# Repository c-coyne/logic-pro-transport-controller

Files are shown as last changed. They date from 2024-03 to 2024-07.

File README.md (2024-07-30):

# Logic Pro Transport Controller

[Logic Pro](https://www.apple.com/logic-pro/) is a professional music recording and production software for Mac that essentially brings an entire music recording studio to your laptop. It's perhaps a bit deceiving given how accessible the software is, but Logic Pro is so professional that a number of big-time musicians have used it to produce albums, including Ed Sheeran (Shape of You), Billie Eilish (most of her music), Taylor Swift (Speak), and The Strokes (Is This It). The DAW (digital audio workstation) is consistently ranked as one of the best available, and was again [rated highly for 2024](https://www.musicradar.com/news/the-best-daws-the-best-music-production-software-for-pc-and-mac).

Likely the most frequently used commands in Logic Pro (at least on the recording side) are contained in a part of the DAW known as the _transport controls_. Below is a snapshot of the transport buttons:

<p align="center">
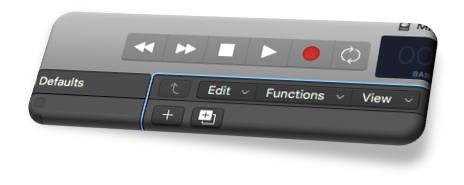
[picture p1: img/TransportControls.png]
Transport controls in Logic Pro
  
</p>

Here's where you'll find options for _return to the beginning_, _rewind_, _fast forward_, _stop_, _play_, and _record_ - in other words, the essential commands for navigating the track. These commands are used so frequently used that you can buy a separate device that facilitates transport control, or a _transport controller_. There are some really interesting controllers on the market, like [this one](https://www.presonus.com/en-US/controllers/control-surface/faderport-series/2777100203.html) from PreSonus. However, these transport controllers are typically rather expensive (anywhere from \$200 to \$500 or more) and aren't customizable. They also tend to be overkill if you're only using a few buttons, plus they require an extra free hand to use.

This is where this project was born. The Logic Pro transport controller designed and built here is entirely customizable, is intended to be operated as a footswitch (so your hands are free to play the music), is a simple plug-and-play (no drivers required), and adds an element of feedback in the form of LEDs. It's certainly more function over form, but its vintage Fender footswitch body and underbody LEDs also make for a cool addition to the recording studio. Happy recording.

## 1. :notes: Project Description
The Logic Pro transport controller detailed here is a simple addition to a vintage 4-button Fender footswitch intended for the Mustang series of guitar amplifiers. I added a microcontroller (Arduino Micro), cast LED strip lights in epoxy underneath the footswitch, and designed and 3D-printed new custom end caps to make room for the additional wiring and new connection (changed to USB-C from MIDI). Further details can be found below.

## 2. :mag: Table of Contents

[Logic Pro Transport Controller](#logic-pro-transport-controller)
- [Logic Pro Transport Controller](#logic-pro-transport-controller)
  - [1. :notes: Project Description](#1-notes-project-description)
  - [2. :mag: Table of Contents](#2-mag-table-of-contents)
  - [3. :beginner: Usage](#3-beginner-usage)
    - [3.1 :1234: Startup sequence](#31-1234-startup-sequence)
    - [3.2 :rewind: Rewind](#32-rewind-rewind)
    - [3.3 :fast_forward: Fastforward](#33-fast_forward-fastforward)
    - [3.4 :end: Back to beginning](#34-end-back-to-beginning)
    - [3.5 :arrow_forward: Play](#35-arrow_forward-play)
    - [3.6 :red_circle: Record](#36-red_circle-record)
    - [3.7 :triangular_flag_on_post: Stop](#37-triangular_flag_on_post-stop)
  - [4. :wrench: Development](#4-wrench-development)
    - [4.1 :clipboard: Development Environment](#41-clipboard-development-environment)
    - [4.2 :construction: File Structure](#42-construction-file-structure)
    - [4.3 :hammer: Build](#43-hammer-build)
    - [4.4 :runner: Deployment](#44-runner-deployment)
  - [5. :pencil: Bill of Materials](#5-pencil-bill-of-materials)
  - [6. :battery: Circuit Diagram / Schematic](#6-battery-circuit-diagram--schematic)
  - [7. :computer: CAD Drawings / 3D Models](#7-computer-cad-drawings--3d-models)
  - [8. :notebook: Notes](#8-notebook-notes)
  - [9. :camera: Gallery](#9-camera-gallery)
  - [10. :books: Credit / Acknowledgment](#10-books-credit--acknowledgment)
  - [11. :e-mail: Contact](#11-e-mail-contact)
  - [12. :scroll: License](#12-scroll-license)

## 3. :beginner: Usage
Configuration for this project is done exclusively in [Cfg_Types.h](include/Cfg_Types.h), where you can configure the following:
- Type of LED
- Number of LEDs
- Brightness
- Connections (switches and LEDs)
- LED color order
- Colors used (ex. init, rewind, fast forward, record, etc.)
- Frequency of the fade in the Play and Stop states
- Turn on / off keyboard emulation (for debugging)
- Commands sent by each switch on the footswitch

While everything here can be configured and adjusted, the default setup is shown below.

**Type of LED:** `WS2811`

**Number of LEDs:** `58`

**Brightness:** `128`

**LED color order:** `GRB`

**Colors used:** `init = white`, `rewind = indigo`, `start = indigo`, `fastfoward = indigo`, `play = green`, `stop = yellow / orange`, `record = red`

**Fade frequency**: `1 Hz`

The instructions below explain how to use the footswitch to control Logic Pro.

<p align="center">
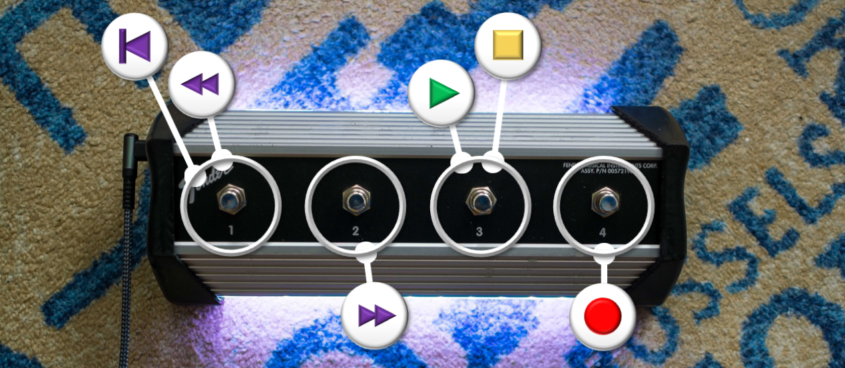
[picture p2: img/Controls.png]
  
</p>

### 3.1 :1234: Startup sequence
When the transport controller is first connected to power, it will go through an LED sequence to indicate initialization. This is currently configured for a few LED pulses followed by a gradual fade to brightness, but this is fully configurable.

<p align="center">
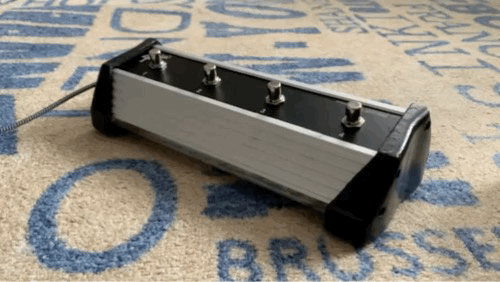
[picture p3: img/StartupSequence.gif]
  
</p>

### 3.2 :rewind: Rewind
The first button moves the playhead back one measure. This will be momentarily acknowledged by one fade cycle of the LEDs.

### 3.3 :fast_forward: Fastforward
The second button moves the playhead forward one measure. This will be momentarily acknowledged by one fade cycle of the LEDs.

<p align="center">
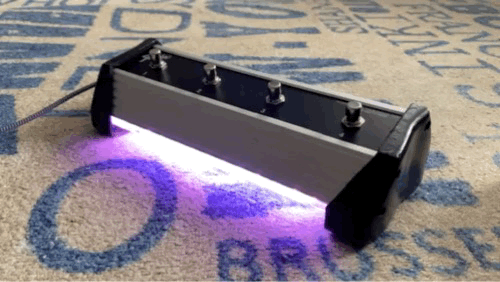
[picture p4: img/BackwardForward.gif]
  
</p>

### 3.4 :end: Back to beginning
Holding the first button moves the playhead back to the beginning of the track. This will be momentarily acknowledged by one fade cycle of the LEDs.

<p align="center">
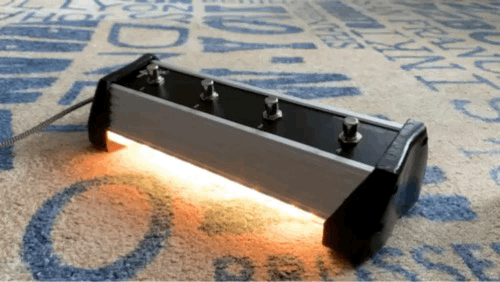
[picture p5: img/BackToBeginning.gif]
  
</p>

### 3.5 :arrow_forward: Play
The third button toggles between play / stop. If the track is currently in the stopped state, pressing the third button will cause the track to play. This will be reflected via a cyclical fading green pattern in the LEDs, which continues as long as the track is still playing.

<p align="center">
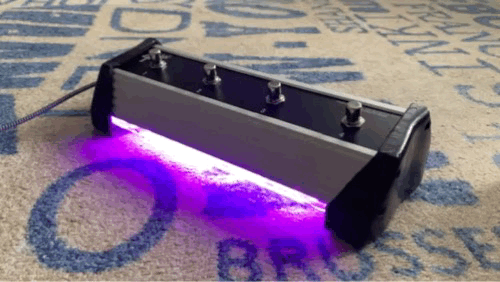
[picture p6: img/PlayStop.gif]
  
</p>

### 3.6 :red_circle: Record
The fourth button starts the track recording. If the track is currently in the stopped state, pressing the fourth button will cause the track to play and start recording. If the track is already playing, this will turn on the recording. Recording will be reflected via a cyclical fading red pattern in the LEDs, which continues as long as the track is still recording.

<p align="center">
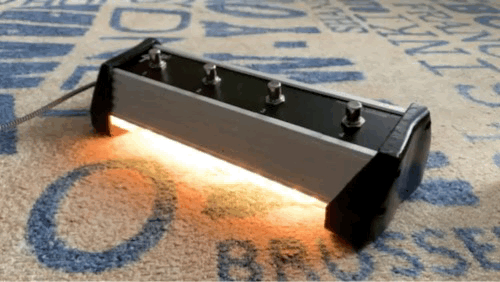
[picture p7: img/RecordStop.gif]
  
</p>

### 3.7 :triangular_flag_on_post: Stop
The third button is used to stop the track when in either the playing or recording state. The stopped state will be acknowledged by yellow / orange LEDs.

## 4. :wrench: Development
The sections below discuss the setup of the project, necessary installations, and how to build and flash the project.

### 4.1 :clipboard: Development Environment
The documentation for this project assumes a setup that includes **Visual Studio Code** and the **PlatformIO extension**. PlatformIO is actually a standalone, cross-platform, open-source system that provides unified debugging, unit testing, static code analysis, and other features, but this project used PlatformIO in the context of a VS Code extension.

### 4.2 :construction: File Structure
Below is an illustration of the file structure used in this project.

```
.
├── cad
│   ├── LeftEndCover.FCStd
│   ├── LeftEndCover.stl
│   ├── RightEndCover.FCStd
│   ├── RightEndCover.stl
├── doc
│   ├── architecture
│   │   └── SystemElectricalSchematic.kicad_sch
│   ├── design
│   │   ├── module
│   │   │   ├── Footswitch.md
│   │   │   ├── LEDController.md
│   │   │   ├── Micro.md
│   │   │   ├── Module.md
│   │   │   ├── SerialCommunication.md
│   │   │   └── Switch.md
│   │   ├── system
│   │   │   ├── SequenceDiagram.md
│   │   └── └── StateDiagram.md
│   └── requirements
│       └── Requirements.md
├── include
│   ├── Cfg_Types.h
│   ├── Footswitch.h
│   ├── LEDController.h
│   ├── Micro.h
│   ├── SerialCommunication.h
│   └── Switch.h
├── src
│   ├── Footswitch.cpp
│   ├── LEDController.cpp
│   ├── main.cpp
│   ├── Micro.cpp
│   ├── SerialCommunication.cpp
│   └── Switch.cpp
├── test
│   └── test_main.cpp
├── platformio.ini
└── README.md
```

| No | Directory | File | Details
|----|---|---|---
| 1  | cad | /*.FCStd | FreeCAD files
| 2  | cad | /*.stl | Stereolithography files for 3D printing (sliced with Cura or similar)
| 3  | doc/architecture | /SystemElectricalSchematic.kicad_sch  | Electrical schematic for the project
| 4  | doc/design/module | /*.md | Detailed design documents for each module
| 5  | doc/design/module | /Module.md | Class diagram
| 6  | doc/design/system | /SequenceDiagram.md | Sequence diagram
| 7  | doc/design/system | /StateDiagram.md | State diagram
| 8  | doc/design/requirements  | /Requirements.md | Functional and non-functional requirements for the project
| 9  | include | /*.h | Class declaration
| 10 | include | /Cfg_Types.h | Configuration file, all configuration is done here
| 11 | src | /*.cpp | Class definition
| 12 | src | /main.cpp | Main program
| 13 | test | /test_main.cpp | Main test file, only dummy tests at the moment
| 14 | . | /platformio.ini | PlatformIO Project Configuration File

### 4.3 :hammer: Build
1. **Clone the Repository**
First, clone the repository to your local machine. You can do this with the following command: `git clone https://github.com/c-coyne/logic-pro-transport-controller.git`
2. **Install PlatformIO**
To build the project, you'll need PlatformIO installed on your system. I used the PlatformIO extension in Visual Studio Code, which includes both the [PlatformIO IDE for VSCode](https://docs.platformio.org/en/latest/integration/ide/vscode.html#ide-vscode) as well as the [PlatformIO Core (CLI)](https://docs.platformio.org/en/latest/core/index.html#piocore), which can be used within the PlatformIO IDE terminal. If you need help installing the PlatformIO extension, check [here](https://docs.platformio.org/en/latest/integration/ide/vscode.html#installation).
3. **Open the Project**
Launch PlatformIO, then open the cloned project folder by choosing _Open Project_ and selecting the project directory.
4. **Resolve Dependencies**
Before you can build the project, you must ensure that all required libraries are installed. These include the **FastLED v3.6.0** (fastled/FastLED@^3.6.0) and **Arduino Keyboard v1.0.5** (arduino-libraries/Keyboard@^1.0.5) libraries, which should both be listed in the _platformio.ini_ file in the main project directory.
5. **Build the Project**
After opening the project, you can build it using the _Build_ button in the PlatformIO window (micro/General/Build) or via the _PlatformIO: Build_ button at the bottom of the screen.

### 4.4 :runner: Deployment
1. **Connect Your Device**
Connect the hardware device (in this case, the Arduino Micro) to your computer via USB.
2. **Check the Connection**
If the device is connected properly, you can see it in the _Quick Access_ window under _Devices_. You can also open a PlatformIO terminal and run `pio device list`. If the device is connected and detected, it will be listed in the output of this command. More information can be found in the [PlatformIO documentation](https://docs.platformio.org/en/stable/core/userguide/device/cmd_list.html).
3. **Set the Upload Port**
PlatformIO should detect the device port by default, so no specification should be needed. However, if you'd like to specify a specific COM port, you can do so in the platform.ini file with the option 
```
upload_port = COM7 ; replace with your port
```
4. **Upload to Your Device**
Upload the project code onto your device using the _Upload_ button in the PlatformIO window (micro/General/Upload) or via the _PlatformIO: Upload_ button at the bottom of the screen.
5. **Monitor the Output**
If needed, use the Serial Monitor to monitor the output from the device in the event of any required debugging.

## 5. :pencil: Bill of Materials

The bill of materials is listed below. Note that I've listed the prices as if each component was purchased new, but the majority of these items I purchased used.

| No | Quantity | Item | Cost | Description
|----|---|---|---|---
| 1  | 1x | [Arduino Micro](https://store-usa.arduino.cc/products/arduino-micro?selectedStore=us) | \$24.90 | Arduino Micro microcontroller board based on the ATmega32U4, selected for its ability to use the Keyboard library
| 2  | 1x | [Fender Footswitch](https://www.fender.com/en-US/parts/footswitches/4-button-footswitch-mustang-series-amplifiers/0080996000.html) | \$89.99 | Four button footswitch designed to be used with the Fender Mustang series of guitar amplifiers
| 3  | 1x | [LED Strip Lights](https://www.amazon.com/gp/product/B0BNN34NCG/ref=ppx_yo_dt_b_search_asin_title?ie=UTF8&th=1) | \$8.99 | 5V WS2812B 3.3ft LED strip lights
| 4  | 1x | [Panel Mount USB Type C 3.1 Adapter](https://www.amazon.com/dp/B09HWSFRP1?ref=ppx_yo2ov_dt_b_product_details&th=1) | \$7.50 | 1ft panel mount USB Type C adapter
| 5  | 1x | [USB C to Micro USB Adapter](https://www.amazon.com/gp/product/B07VBV1PY5/ref=ppx_yo_dt_b_search_asin_title?ie=UTF8&psc=1) | \$6.99 | Adapter to convert from USB C (external connection) to Micro USB (Arduino Micro connection)
| 6  | 1x | [USB C Cable](https://www.amazon.com/gp/product/B094YDZQ1C/ref=ppx_yo_dt_b_search_asin_title?ie=UTF8&psc=1) | \$9.99 | Cable to connect the footswitch to the laptop
| 7  | 1x | [Epoxy](https://www.amazon.com/gp/product/B07S1MLQMJ/ref=ppx_yo_dt_b_search_asin_title?ie=UTF8&psc=1) | \$13.99 | Epoxy for casting the underbody LEDs
| 8  | 1x | Jumper wires | - | -
| 9  | 1x | Prototyping breadboard (if desired) | - | - 

## 6. :battery: Circuit Diagram / Schematic
The circuit for this project is very simple, and most of the circuit is already provided by the production Fender footswitch. The footswitch uses a 5-pin DIN connector for MIDI connection, where each pushbutton switch on the footswitch pulls the respective line to ground. The circuit board inside the footswitch makes each of the DPDT switch terminals easily accessible, which facilitated additional solder connections to the Arduino Micro. Therefore, assembling the electrical aspects of the project was straightforward, but feel free to check out the [schematic](doc/architecture/SystemElectricalSchematic.kicad_sch) for more details.

## 7. :computer: CAD Drawings / 3D Models
The STL files used in this project are available in the _cad_ directory. These files fit the vintage model of the Fender 4-button footswitch and were specifically designed to accommodate the thickness of my resulting epoxy pad underneath the footswitch. If you want to build this project and your epoxy pad isn't ~0.3", you'll need to adjust the design slightly.

I've included both the STL files (to facilitate 3D printing) as well as the FreeCAD files for modification of the design. Note that the left end cover was born out of the right end cover, so the final step should be mirroring the main body about the XZ plane.

## 8. :notebook: Notes
There really is no limit to how this project might be extended, and below are a few ideas if time permitted:
- more functionality in the underbody LEDs (Disco mode? Lava lamp simulation?)
- more functionality in the switches (double-click, hold, two switches at once, etc.)
- an underlying menu with the ability to switch "modes" and have access to even more features
- a built-in potentiometer to adjust the LED brightness in real time instead of being defined as a macro
- a GUI for configuration

## 9. :camera: Gallery

<p float="left">
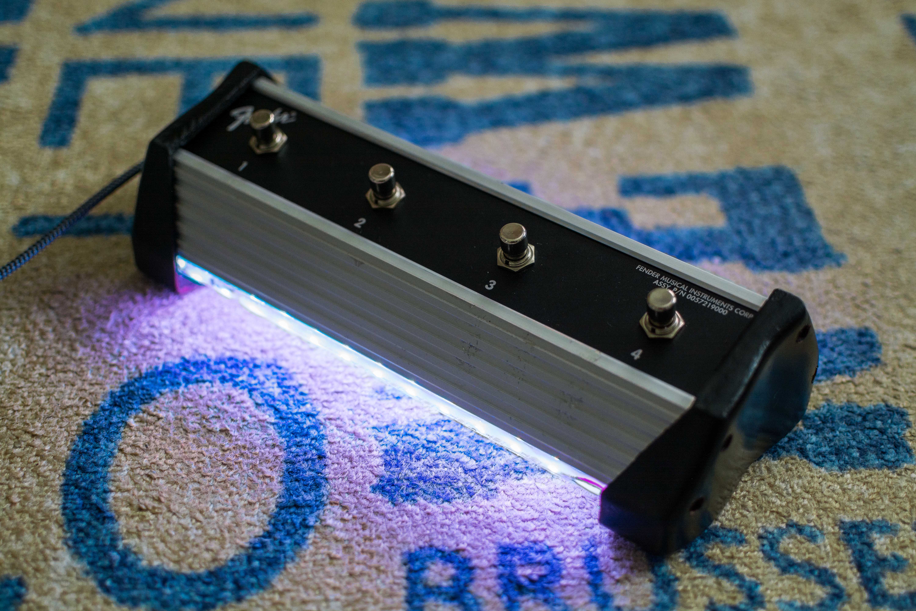
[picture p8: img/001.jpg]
    
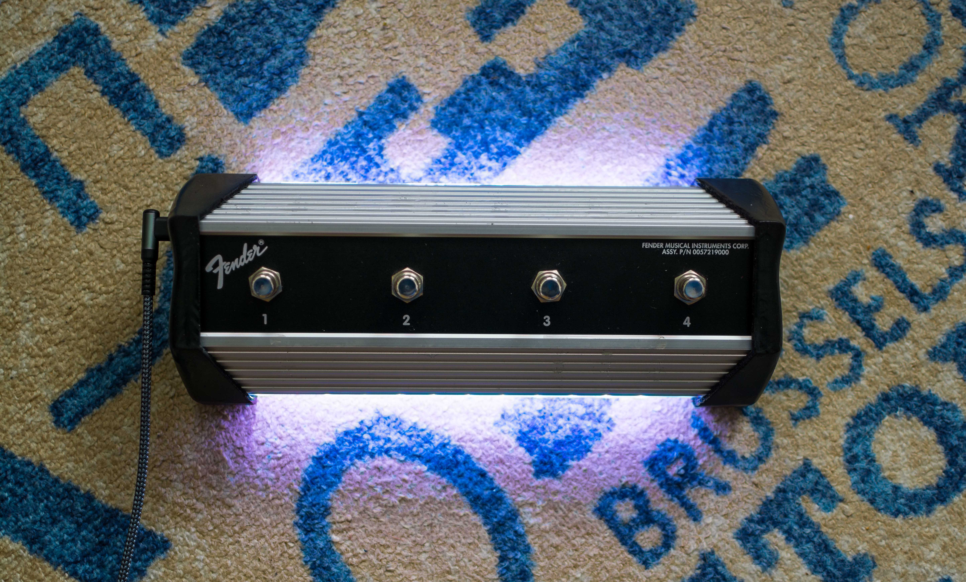
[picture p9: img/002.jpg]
    
</p>
<p float="left">
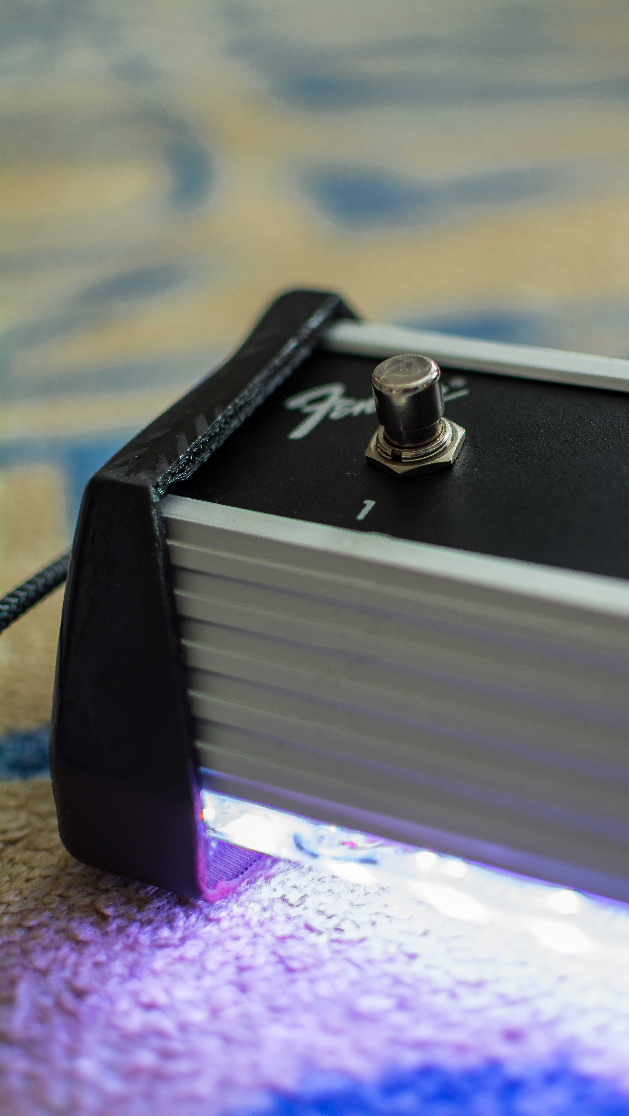
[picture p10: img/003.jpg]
    
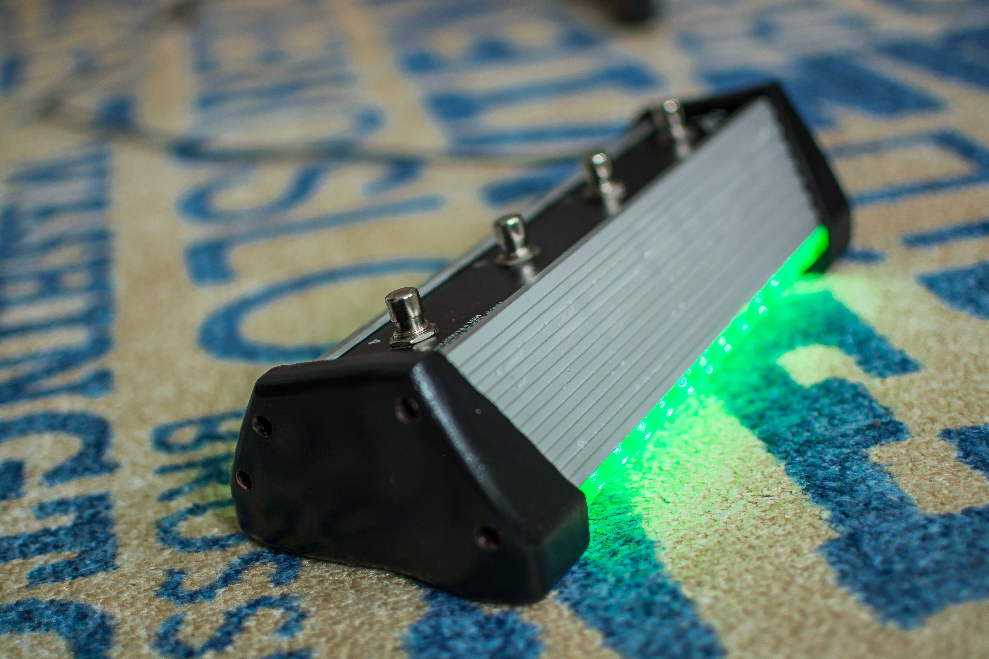
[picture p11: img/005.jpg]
    
</p>
<p float="left">
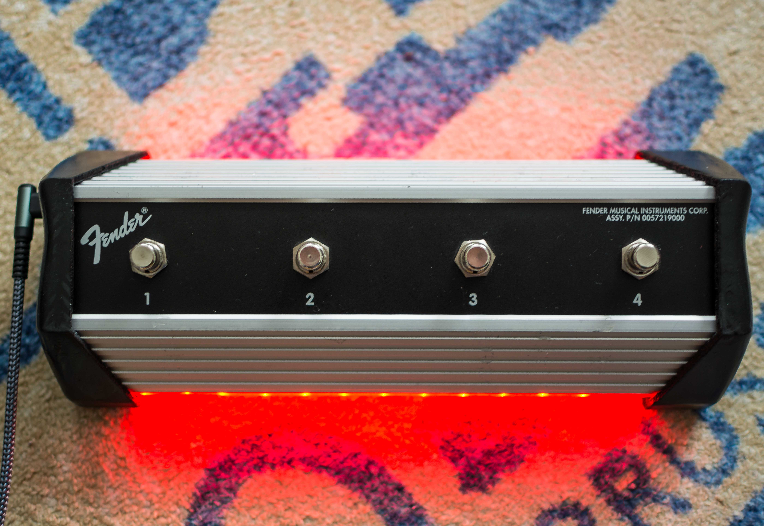
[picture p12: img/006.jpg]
    
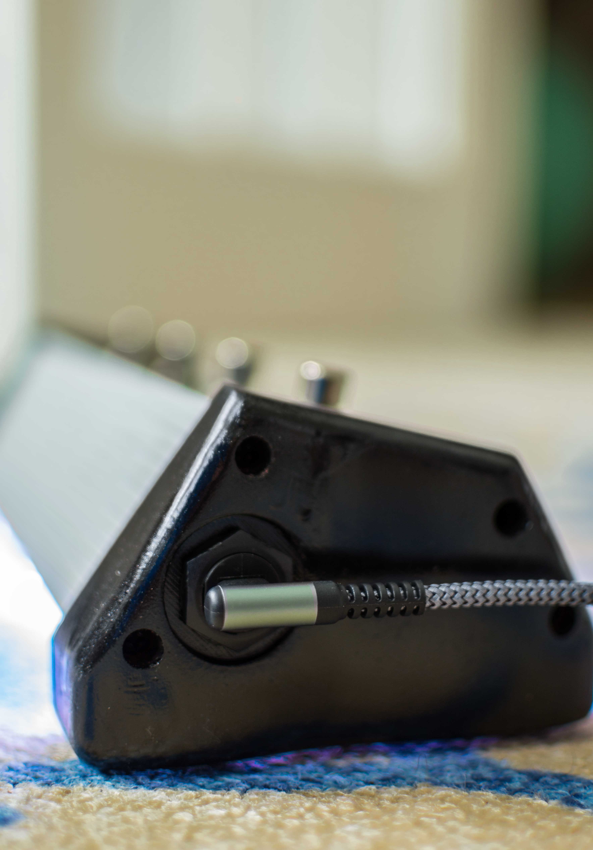
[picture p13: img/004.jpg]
    
</p>
<p float="left">
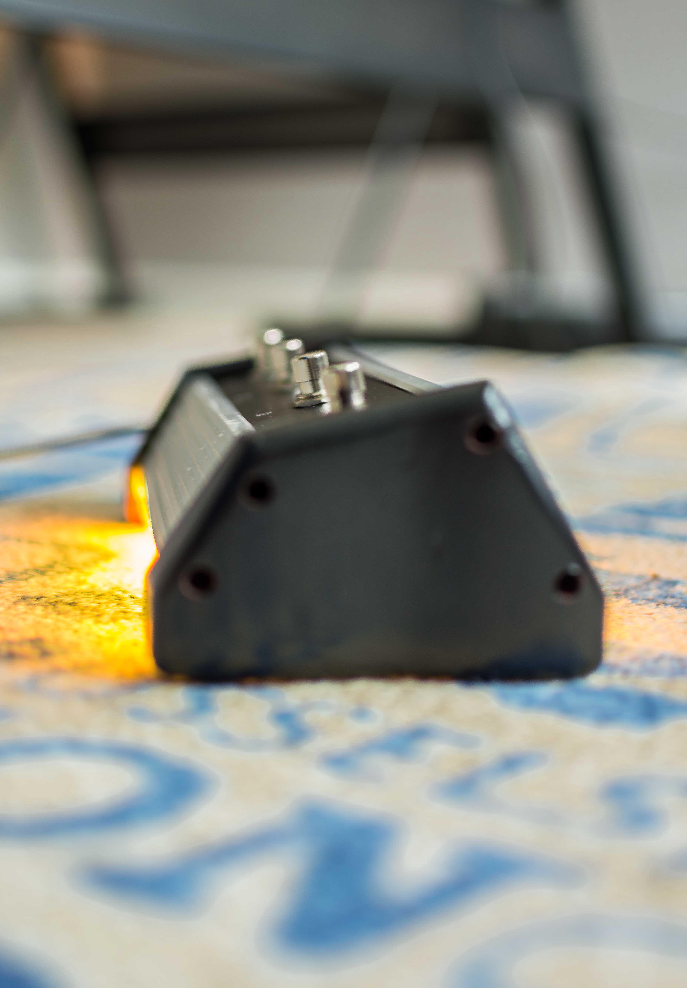
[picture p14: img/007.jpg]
    
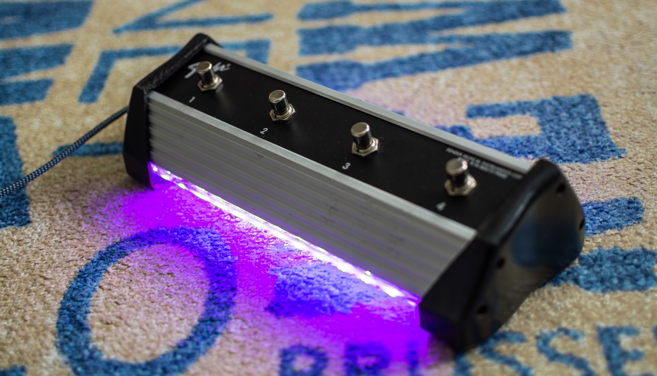
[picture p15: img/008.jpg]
    
</p>
<p float="left">
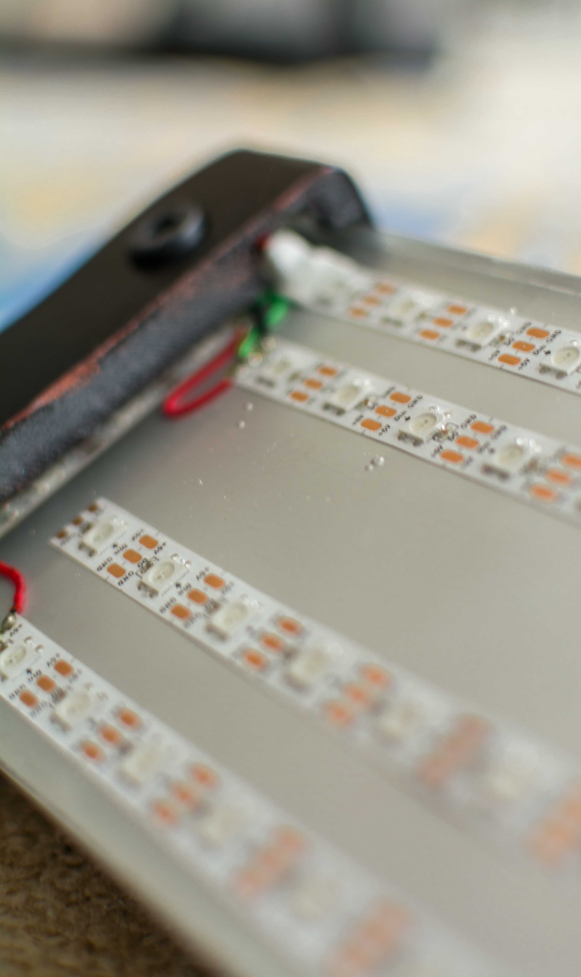
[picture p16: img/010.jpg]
    
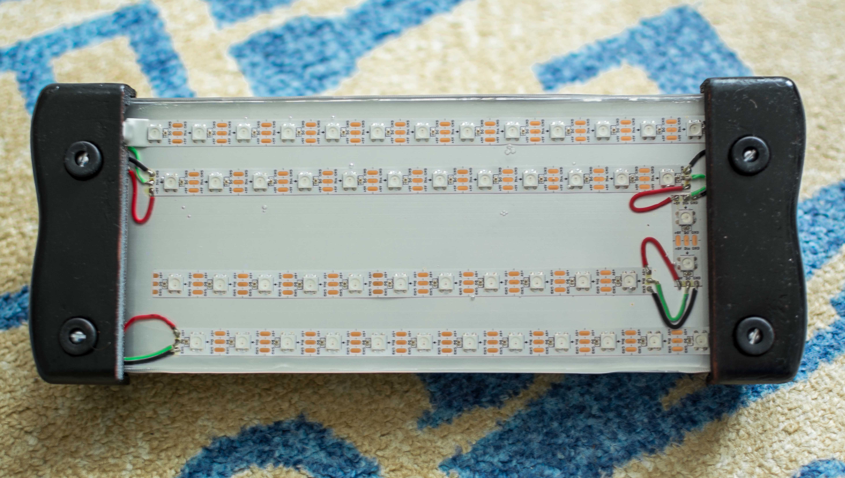
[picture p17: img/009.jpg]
    
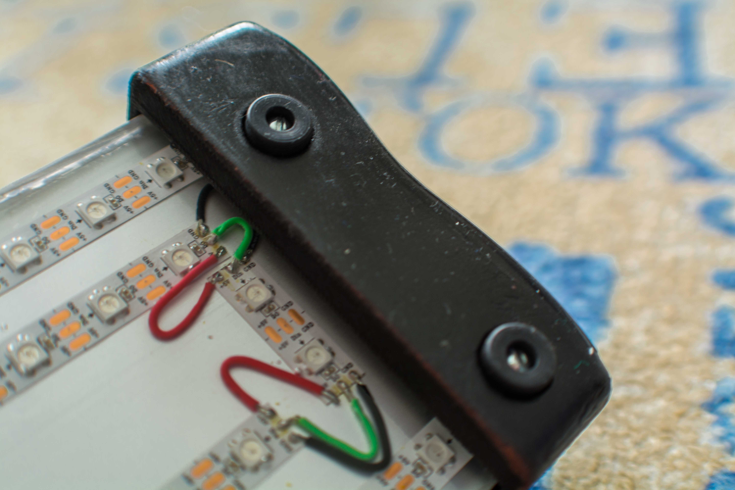
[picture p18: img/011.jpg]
    
</p>

## 10. :books: Credit / Acknowledgment

**FastLED**: This project uses the [FastLED 3.6.0 library](https://github.com/FastLED/FastLED), which was created to very easily and efficiently control a range of LED types. While this Logic Pro Transport Controller project only uses the library to control WS2811 LEDs, the FastLED library supports a wide variety of LED chipsets, including Neopixel (WS2812B), WS2801, APA102, and many more. FastLED is available through the PlatformIO Library Manager, but you can also check it out [here](https://github.com/FastLED/FastLED).

**Keyboard**: One of the primary features of this project is the ability to send commands to the connected laptop to simulate a keyboard, and the Arduino Keyboard library was used for this purpose. Like the FastLED library, the Arduino Keyboard library is available through the PlatformIO Library Manager.

## 11. :e-mail: Contact

Christopher Coyne: christopher.w.coyne@gmail.com  
Project Link: https://github.com/c-coyne/logic-pro-transport-controller

## 12. :scroll: License
This project is licensed under the [MIT License](https://opensource.org/license/MIT).

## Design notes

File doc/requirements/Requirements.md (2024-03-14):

# Project Requirements

## Functional Requirements
* **FR_001**: When Button 1 on the Fender footswitch is pressed, the system shall detect the button press within 10 ms.
* **FR_002**: When the Button 1 button press is detected by the system, the underbody LEDs shall emit Indigo light.
* **FR_003**: When the Button 1 button press is detected by the system, the underbody LEDs shall blink once with gradual fade off and back on, with total cycle time of 0.5 seconds.
* **FR_004**: When the Button 1 button press is detected by the system, the system shall generate a keyboard shortcut "," (Logic Pro X: Rewind).
* **FR_005**: When Button 1 is held down for more than 1 second, the system shall generate a keyboard shortcut "Return" (Logic Pro X: Go To Beginning).
* **FR_006**: When Button 1 is held down for more than 1 second, the underbody LEDs shall emit Indigo light.
* **FR_007**: When Button 1 is held down for more than 1 second, the system shall remain at their current state with no fading.
* **FR_008**: When Button 2 on the Fender footswitch is pressed, the system shall detect the button press within 10 ms.
* **FR_009**: When the Button 2 button press is detected by the system, the underbody LEDs shall emit Indigo light.
* **FR_010**: When the Button 2 button press is detected by the system, the underbody LEDs shall blink once with gradual fade off and back on, with total cycle time of 0.5 seconds.
* **FR_011**: When the Button 2 button press is detected by the system, the system shall generate a keyboard shortcut "." (Logic Pro X: Forward).
* **FR_012**: When Button 3 on the Fender footswitch is pressed, the system shall detect the button press within 10 ms.
* **FR_013**: When the Button 3 button press is detected by the system, the underbody LEDs shall emit Green light when playing and Orange light when stopping.
* **FR_014**: When the Button 3 button press is detected by the system, if the system is playing music, the underbody LEDs shall pulsate at 0.2-1.0 Hz.
* **FR_015**: When the Button 3 button press is detected by the system, the system shall generate a keyboard shortcut "Space bar" (Logic Pro X: Play / Stop).
* **FR_016**: When Button 4 on the Fender footswitch is pressed, the system shall detect the button press within 10 ms.
* **FR_017**: When the Button 4 button press is detected by the system, the underbody LEDs shall emit Red light.
* **FR_018**: When the Button 4 button press is detected by the system, the underbody LEDs shall pulsate at 0.2-1.0 Hz.
* **FR_019**: When the Button 4 button press is detected by the system, the system shall generate a keyboard shortcut "r" (Logic Pro X: Record).

## Non-Functional Requirements
* **NFR_001**: The system shall be operational with only one cable connecting the Fender footswitch to the laptop.
* **NFR_002**: The system shall be reprogrammable via the single cable connecting the Fender footswitch to the laptop.
* **NFR_003**: After connecting the Fender footswitch to the laptop using the designated cable, the system shall start running without requiring additional configuration.
* **NFR_004**: The project shall send the shortcut commands for a Macbook Pro laptop.

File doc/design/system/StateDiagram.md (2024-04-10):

# State diagram

This document details the state machine implemented in this project, first with a description of each of the states, then with a state diagram. 

Note the distinction between the **INIT** initialization state and the **START** state. From an embedded software perspective, these may sound similar. However, from a musician's perspective, **INIT** is simply the default start-up condition of the transport controller, whereas **START** is a return to the start / beginning of the track.

## State descriptions

**INIT:** this is the initialization state. On power-on reset, the microcontroller is in the INIT state.
<strong style="color:purple">START:</strong>  this state entails a return to the beginning of the track.
<strong style="color:purple">REWIND:</strong> this is the resulting state after stepping back in the track by one bar.
<strong style="color:purple">FASTFORWARD:</strong> this is the resulting state after stepping forward in the track by one bar.
<strong style="color:green">PLAY:</strong> the track is actively playing.
<strong style="color:orange">STOP:</strong> the track is stopped.
<strong style="color:red">RECORD:</strong> the track is recording.

## Diagram

```mermaid
stateDiagram-v2
    classDef init fill:white,font-weight:bold
    classDef start fill:indigo,color:white,font-weight:bold
    classDef rewind fill:indigo,color:white,font-weight:bold
    classDef fastforward fill:indigo,color:white,font-weight:bold
    classDef play fill:green,color:white,font-weight:bold
    classDef stop fill:orange,color:white,font-weight:bold
    classDef record fill:red,color:white,font-weight:bold

    [*] --> INIT
    STOP --> START : Switch 1 (long)
    STOP --> REWIND : Switch 1 (short)
    STOP --> FASTFORWARD : Switch 2
    STOP --> PLAY : Switch 3
    STOP --> RECORD : Switch 4

    PLAY --> STOP : Switch 3
    PLAY --> RECORD : Switch 4

    RECORD --> STOP: Switch 3

    START --> FASTFORWARD : Switch 2
    START --> PLAY : Switch 3
    START --> RECORD : Switch 4

    INIT --> START : Switch 1 (long)
    INIT --> REWIND : Switch 1 (short)
    INIT --> FASTFORWARD : Switch 2
    INIT --> PLAY : Switch 3
    INIT --> RECORD : Switch 4
    
    REWIND --> START : Switch 1 (long)
    REWIND --> FASTFORWARD : Switch 2
    REWIND --> PLAY : Switch 3
    REWIND --> RECORD : Switch 4

    FASTFORWARD --> REWIND : Switch 1 (short)
    FASTFORWARD --> START : Switch 1 (long)
    FASTFORWARD --> PLAY : Switch 3
    FASTFORWARD --> RECORD : Switch 4

    class INIT init
    class START start
    class REWIND rewind
    class FASTFORWARD fastforward
    class PLAY play
    class STOP stop
    class RECORD record
```

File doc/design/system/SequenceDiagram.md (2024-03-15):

# Sequence diagram

```mermaid
sequenceDiagram
    
    create participant main

    create participant micro
    main->>micro: 1. Micro micro(switchPins)
    
    create participant footswitch
    micro->>footswitch: 2. Footswitch footSwitch(switchPins)
    
    create participant switch0
    footswitch->>switch0: 3. Switch switch0(0, switchPins[0])
    
    create participant switch1
    footswitch->>switch1: 4. Switch switch0(1, switchPins[1])
    
    create participant switch2
    footswitch->>switch2: 5. Switch switch0(2, switchPins[2])
    
    create participant switch3
    footswitch->>switch3: 6. Switch switch0(3, switchPins[3])
    
    create participant ledController
    micro->>ledController: 7. LEDController ledController()
    
    create participant serialCommunication
    micro->>serialCommunication: 8. SerialCommunication serialCommunication()
    
    main->>micro: 9. micro.microInit()

    micro->>micro: 10. mainState = STATE_INIT
    micro->>ledController: 11. ledController.LEDControllerInit()

    ledController->>ledController: 12. setBrightness(0);
    ledController->>ledController: 13. setLEDColor(INIT_COLOR);
    ledController->>ledController: 14. fade(300, 2, true, false);

    loop every ms
        main->>micro: 15. micro.checkFootswitch()
        micro->>+footswitch: 16. footSwitch.checkSwitches()
        footswitch->>+switch0: 17. switch0.isPressed()
        switch0-->>-footswitch: 18. return: true/false
        footswitch->>+switch1: 19. switch1.isPressed()
        switch1-->>-footswitch: 20. return: true/false
        footswitch->>+switch2: 21. switch2.isPressed()
        switch2-->>-footswitch: 22. return: true/false
        footswitch->>+switch3: 23. switch3.isPressed()
        switch3-->>-footswitch: 24. return: true/false
        footswitch-->>-micro: 25. return: switchID
        alt switchID != SWITCH_NONE
            micro->>micro: 26. update mainState
            micro->>serialCommunication: 27. serialCommunication.sendCommand(id)
            micro->>ledController: 28. ledController.setLEDColor(color)
            micro->>ledController: 29. ledController.setBrightness(BRIGHTNESS)
        end
        main->>micro: 30. micro.mainFunction()
    end
```

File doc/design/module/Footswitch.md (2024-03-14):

# Footswitch Class

## Class Description

The `Footswitch` class represents a physical [Fender 4-button footswitch for the Mustang series guitar amplifiers](https://www.fender.com/en-US/parts/footswitches/4-button-footswitch-mustang-series-amplifiers/0080996000.html). It's comprised for four [Switch](Switch.md) objects representing the four pushbutton switches.

## Attributes

- `switch0`: The first pushbutton switch on the footswitch.
- `switch1`: The second pushbutton switch on the footswitch.
- `switch2`: The third pushbutton switch on the footswitch.
- `switch3`: The fourth pushbutton switch on the footswitch.

## Methods

### `Footswitch(int switchPins[4])`
- **Description**: This is the constructor for the `Footswitch` class. It initializes a new instance of a `Switch`, which sets up four `Switch` objects per below. Each of the four switch pins are then configured with an internal pull-up resistor so that the default state is `HIGH`.
The switch objects are:
    - `switch0(0, switchPins[0])` --> id = 0, pin = switchPins[0]
    - `switch1(1, switchPins[1])` --> id = 1, pin = switchPins[1]
    - `switch2(2, switchPins[2])` --> id = 2, pin = switchPins[2]
    - `switch3(3, switchPins[3])` --> id = 3, pin = switchPins[3]
- **Input Parameters**: 
    - `int switchPins[4]`: an array of integers defining which pin each switch is connected to (switch0 = element 0, switch1 = element 1, etc.).
- **Return Type**: Does not return a value.

### `~Footswitch()`
- **Description**: This is the destructor for the `Footswitch` class. It cleans up the instance of the `Footswitch` when it's no longer needed.
- **Input Parameters**: None.
- **Return Type**: Does not return a value.

### `SwitchID checkSwitches()`
- **Description**: This method reads the state of each of the switches on the footswitch. If a switch is pressed, this method returns the corresponding switch ID. If no switch is pressed, it returns `SWITCH_NONE`. Note that `switch0` has different functionality depending on its press duration: if it's pressed <1 second, it sends a `SWITCH_0` reponse; otherwise, if it's pressed >=1 second, it sends a `SWITCH_0_LONG` response. Also note that there is an inherent priority built into the method: `switch0` > `switch1` > `switch2` > `switch3`.
- **Input Parameters**: None.
- **Return Type**: Returns the `SwitchID` of the switch that is pressed, otherwise `SWITCH_NONE`.

## Dependencies

This class has a dependency on the [Switch](Switch.md) class.

## Examples
```
// create a new footswitch object
int switchPins[4] = { 5, 6, 7, 8 };
FootSwitch fs(switchPins);

// check the state of the footswitch
SwitchID switchId = fs.checkSwitches();

// take action according to which switch is pressed
switch(switchId) {
    case SWITCH_0:
        // execute when switch0 is pressed (short press)
    case SWITCH_0_LONG:
        // execute when switch0 is pressed (long press)
    case SWITCH_1:
        // execute when switch1 is pressed
    case SWITCH_2:
        // execute when switch2 is pressed
    case SWITCH_3:
        // execute when switch3 is pressed
    default:
        // default case
}
```

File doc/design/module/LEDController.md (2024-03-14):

# LEDController Class

## Class Description

The LEDController class represents a physical string of LEDs, where each SMD 5050 LED has an integrated driver IC that allows for independent control of color and brightness. This class uses the FastLED library to facilitate control of the LED string.

## Attributes

- `CRGB leds[NUM_LEDS]`: array of CRGB structs representing the LED string of size `NUM_LEDS`
- `float mainInterval`: the `mainInterval` is used to control the cycle time of the LED pulse detailed in `LEDController::internalFade()`
- `float mainBrightness`: the `mainBrightness` is used to keep track of the underbody LED brightness in between calls to `LEDController::internalFade()`

## Methods

### `LEDController()`
- **Description**: This is the constructor for the `LEDController` class. It initializes a new instance of an `LEDController`.
- **Input Parameters**: None.
- **Return Type**: Does not return a value.

### `~LEDController()`
- **Description**: This is the destructor for the `LEDController` class. It cleans up the instance of the `LEDController` when it's no longer needed.
- **Input Parameters**: None.
- **Return Type**: Does not return a value.

### `void LEDControllerInit()`
- **Description**: Initializes the LEDController object.
- **Input Parameters**: None.
- **Return Type**: Does not return a value.

### `void setBrightness(int brightness)`
- **Description**: Sets the brightness of the LED string.
- **Input Parameters**:
    - `int brightness`: Value from 0 (darkest) to 255 (brightest)
- **Return Type**: Does not return a value.

### `void setLEDColor(CRGB color)`
- **Description**: Sets the color of the LED string.
- **Input Parameters**:
    - `CRGB color`: color to which the LED string should be set. All 168 pre-defined colors are detailed in _pixeltypes.h_, but custom colors can be developed as well.
.- **Return Type**: Does not return a value.

### `void fade(int duration, int count, bool increasing, bool endBright)`
- **Description**: Fades the LED string from light to dark to light (`increasing = false`) or from dark to light to dark (`increasing = true`) a total of `count` times. If `endBright` is true, the LED string will fade back up to `BRIGHTNESS` after `count` fade cycles.
- **Input Parameters**:
    - `int duration`: cycle time for the full fade (bright to dark to bright or dark to bright to dark) in seconds
    - `int count`: number of fade cycles to execute
    - `bool increasing`: variable to determine if the cycles should start dark (`increasing = true`) or bright (`increasing = false`)
    - `bool endBright`: determines if the fade cycle should end bright or not. This is only meaningful if `increasing == false`
- **Return Type**: Does not return a value.

### `void internalFade()`
- **Description**: This function is used to gradually fade the LED string up and down "in the background", i.e. while no switches are pressed. This is used in the states `STATE_PLAY` and `STATE_RECORD`.
- **Input Parameters**: None
- **Return Type**: Does not return a value.

## Dependencies

This class does not have any dependencies on other classes.

## Examples
```
// create a new LEDController object
LEDController ledController();

// set brightness of LED string
ledController.setBrightness(255);

// set color of LED string
ledController.setColor(CRGB::White);
```

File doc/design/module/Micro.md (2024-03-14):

# Micro Class

## Class Description

The Micro class represents the microcontroller (in this project, Arduino Micro board based on the ATmega32U4).

## Attributes

- `Footswitch footSwitch`: the [Footswitch](Footswitch.md) member variable, representing the Fender footswitch
- `LEDController ledController`: the [LEDController](LEDController.md) member variable, representing the LED string
- `SerialCommunication serialCommunication`: the [SerialCommunication](SerialCommunication.md) member variable, enabling USB communication with the connected laptop
- `State mainState`: this variable is used to keep track of the current state in the state machine

## Methods

### `void microInit()`
- **Description**: Initializes the microcontroller state machine to `STATE_INIT` and initializes the `LEDController ledController` member variable.
- **Input Parameters**: None.
- **Return Type**: Does not return a value.

### `void checkFootswitch()`
- **Description**: This method polls the footswitch for new input, then acts on it accordingly. If no switches are pressed, there is no action to be taken. If a switch is pressed, then the `mainState` is assessed to determine the necessary action to take. This typically involves setting the LED string to a specified color and sending a command to the connected laptop.
- **Input Parameters**: None.
- **Return Type**: Does not return a value.

### `void mainFunction()`
- **Description**: This function checks the current state in the state machine via `mainState` and executes accordingly. In this project, this is only used to pulsate the LED string when in the `STATE_PLAY` and `STATE_RECORD` states.
- **Input Parameters**: None.
- **Return Type**: Does not return a value.

## Dependencies

This class requires the [Footswitch](Footswitch.md), [LEDController](LEDController.md), and [SerialCommunication](SerialCommunication.md) classes.

## Examples
```
// create a new micro object
int switchPins[] = { 5, 6, 7, 8 };
Micro micro(switchPins);

// poll for input from the footswitch
micro.checkFootswitch();

// execute actions per the state machine
micro.mainFunction();
```

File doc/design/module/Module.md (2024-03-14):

# Module design

```mermaid
classDiagram
    Footswitch o-- Switch
    Micro --> Footswitch
    Micro --> LEDController
    Micro --> SerialCommunication
    class Switch{
        -int id
        -int pin
        +bool isPressed()
    }
    class Footswitch{
        -Switch switch0
        -Switch switch1
        -Switch switch2
        -Switch switch3
        +SwitchID checkSwitches()
    }
    class Micro{
        -Footswitch footswitch
        -LEDController ledController
        -SerialCommunication serialCommunication;
        -State mainState
        +void microInit()
        +void checkFootswitch()
        +void mainFunction()
    }
    class LEDController{
        -CRGB leds[NUM_LEDS]
        -float mainInterval
        +float mainBrightness
        +void LEDControllerInit()
        +void setBrightness(int brightness)
        +void setLEDColor(CRGB color)
        +void fade(int duration, int count, bool increasing, bool endBright)
        +void internalFade()
    }
    class SerialCommunication{
        +void sendCommand(SwitchID id)
    }
```

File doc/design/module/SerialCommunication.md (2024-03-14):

# SerialCommunication Class

## Class Description

The SerialCommunication class represents the serial communication between the microcontroller and the connected laptop via USB. All emulated keyboard strokes are sent via the SerialCommunication class.

## Attributes

None.

## Methods

### `void sendCommand(SwitchID id)`
- **Description**: This method receives a switch ID and sends the appropriate message to the connected laptop via USB. Each message - configured in Cfg_Types.h - is an emulation of keyboard presses enabled by the Arduino keyboard library. Note that all serial communication can be turned on or off via the `SERIAL_ENABLED` macro in Cfg_Types.h
- **Input Parameters**: 
    - `SwitchID id`: the switch ID is used to determine which message to send.
- **Return Type**: Does not return a value.

## Dependencies

This class does not have any dependencies on other classes.

## Examples
```
// create a new SerialCommunication object
SerialCommunication sc();

// send a message
SwitchID switchId = SWITCH_1;
sc.sendCommand(switchId);
```

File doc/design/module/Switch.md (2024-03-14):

# Switch Class

## Class Description

The `Switch` class represents a physical pushbutton switch with unique identifier `id` and connection pin `pin`. The switch has two possible states: _pressed_ and _not pressed_. The default state is _not pressed_.

## Attributes

- `state`: A boolean attribute representing the state of the switch. `true` indicates the switch is _pressed_ and `false` indicates that it's _not pressed_.

## Methods

### `Switch(int idValue, int pinValue)`
- **Description**: This is the constructor for the `Switch` class. It initializes a new instance of a `Switch`, setting the id to `idValue` and the pin to `pinValue`.
- **Input Parameters**: 
    - `int idValue`: the unique identifier of the switch
    - `int pinValue`: the GPIO pin that the switch is connected to
- **Return Type**: Does not return a value.

### `~Switch()`
- **Description**: This is the destructor for the `Switch` class. It cleans up the instance of the `Switch` when it's no longer needed.
- **Input Parameters**: None.
- **Return Type**: Does not return a value.

### `bool getState()`
- **Description**: This method returns the current state of the `Switch`.
- **Input Parameters**: None.
- **Return Type**: Returns a boolean indicating the current state of the `Switch`. Returns `true` if the switch is pressed and `false` if it is not pressed. The default state is `false` (not pressed).

## Dependencies

This class does not have any dependencies on other classes.

## State diagram

```mermaid
stateDiagram-v2
    s1: getState() = false
    s2: getState() = true
    s1 --> s2 : Button pushed
    s2 --> s1 : Button released
```

## Examples

```
// create a new switch object with ID = 0 and GPIO pin = 8
Switch mySwitch(0, 8);

// check the state of the switch
bool currentState = mySwitch.getState();
if (currentState) {
  // code here runs if the switch is pressed
} else {
  // code here runs if the switch is not pressed
}
```

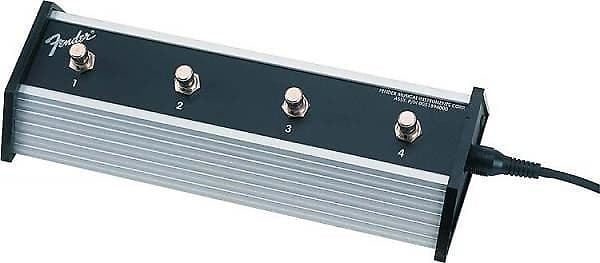
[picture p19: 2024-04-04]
img/FenderFootswitch.png

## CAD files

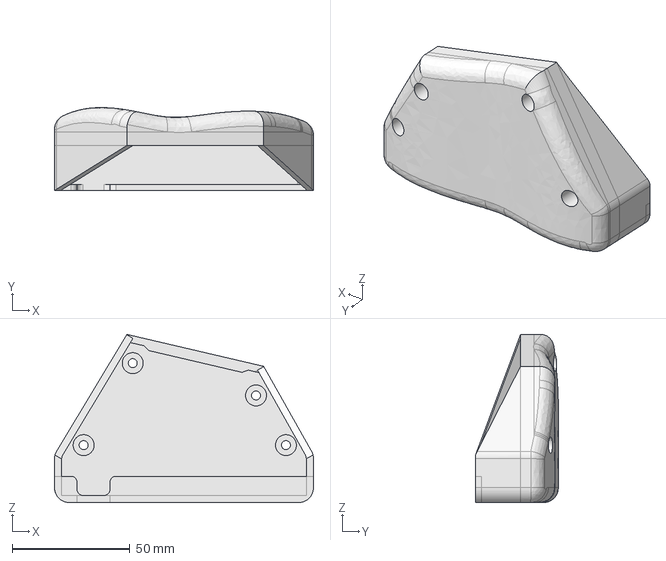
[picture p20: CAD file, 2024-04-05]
cad/RightEndCover.FCStd
109.9 x 35.2 x 71.4 mm

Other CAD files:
cad/RightEndCover.stl

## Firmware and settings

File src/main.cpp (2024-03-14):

/****************************************************
 *  Include files                                   *
 ****************************************************/
#include <Arduino.h>
#include <Keyboard.h>
#include "Micro.h"
#include "Cfg_Types.h"

/****************************************************
 *  Local variables                                 *
 ****************************************************/

int switchPins[] = {SWITCH0_PIN, SWITCH1_PIN, SWITCH2_PIN, SWITCH3_PIN};
Micro micro(switchPins);

/****************************************************
 *  Setup                                           *
 ****************************************************/

void setup() {

  micro.microInit(); // Initialize the microcontroller

}

/****************************************************
 *  Main                                            *
 ****************************************************/

void loop() {

  micro.checkFootswitch(); // [FR_001, FR_008, FR_012, FR_016]
  micro.mainFunction();
  delay(1);

}

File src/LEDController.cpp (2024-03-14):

/*=====================================================================================*\
| Author:   Christopher Coyne                                         March 13th, 2024  |
| --------------------------------------------------------------------------------------|
| MODULE:     [ LEDController ]                                                         |
| --------------------------------------------------------------------------------------|
| DESCRIPTION:                                                                          |
|    LEDController class                                                                |
| --------------------------------------------------------------------------------------|
\*=====================================================================================*/

/****************************************************
 *  Include files                                   *
 ****************************************************/
#include "LEDController.h"

/****************************************************
 *  Constructor / destructor                        *
 ****************************************************/

LEDController::LEDController() {

    FastLED.addLeds<LED_TYPE, LED_PIN, COLOR_ORDER>(leds, NUM_LEDS).setCorrection( TypicalLEDStrip ); // Add a clockless based CLEDController instance
    FastLED.setBrightness(BRIGHTNESS);

}

LEDController::~LEDController() {}

/****************************************************
 *  Member functions                                *
 ****************************************************/

void LEDController::internalFade() {

    // Keep track of whether the LEDs are fading up or down
    static bool increasing = false;

    // Change fade direction if necessary
    if (mainBrightness <= 1) { increasing = true; }
    else if (mainBrightness >= BRIGHTNESS) { increasing = false; }

    // Set brightness of LED string
    mainBrightness = (increasing) ? mainBrightness + mainInterval : mainBrightness - mainInterval;
    setBrightness(mainBrightness);

    return;
}

void LEDController::fade(int duration, int n, bool increasing, bool endBright) {

    // Set up interval and initial brightness, initialize fade count
    float interval = float(BRIGHTNESS) / (duration / 2.);
    float brightness = (increasing) ? 0. : float(BRIGHTNESS);
    int count = 0;
    bool countLow = (increasing) ? true : false;

    // Gradually fade the LED up and down {n} times
    while (count < n) {

        setBrightness(brightness);

        if (increasing) {
            brightness += interval;
            if (brightness > BRIGHTNESS) {
                increasing = false;
                if (!countLow) {count++;}
                }
        } else {
            brightness -= interval;
            if (brightness <= 1) {
                increasing = true;
                if (countLow) {count++;}
                }
        }

        delay(1); // Wait 1 ms between cycles
    }

    // If the LED strip should end bright (vs. dark)
    if (endBright) {       

        while (brightness < BRIGHTNESS) {
            setBrightness(brightness);
            brightness += interval;
            delay(1);
        }

    }

    return;
}

void LEDController::LEDControllerInit() {

    // Initialize main variables
    mainBrightness = BRIGHTNESS;
    mainInterval = BRIGHTNESS / (0.5 * FADE_DURATION);

    // Set initial LED brightness and color
    setBrightness(0);
    setLEDColor(INIT_COLOR);

    // Fade LED strip up and down two times as an init sequence
    fade(300, 2, true, false);

    // Fade LEDs up to BRIGHTNESS to indicate device is ready
    float interval = float(BRIGHTNESS) / 1000.;
    float brightness = 0;
    for (int i=0; i<1001; i++) {
        setBrightness(brightness);
        brightness += interval;
        delay(1);
    }

    return;
}

void LEDController::setBrightness(int brightness) {

    FastLED.setBrightness(brightness);
    FastLED.show();

    return;
}

void LEDController::setLEDColor(CRGB color) {

    fill_solid( leds, NUM_LEDS, color);
    FastLED.show();

    return;
}

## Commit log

2024-03-07 Added classes for Footswitch, LEDController, Micro, and Switch, added FastLED library
2024-03-07 Set up Unity test framework for testing on native host
2024-03-07 Added documentation framework, including initial requirements and detailed design documents
2024-03-08 Added ArduinoNative library to unit_test environment to fix unit testing build errors
2024-03-08 Set up communication to monitor GPIOs from Micro-->Footswitch-->Switch
2024-03-08 Added initial LED control from Micro class, removed testing due to native / on-target clash
2024-03-09 Added initialization sequence for LED strip
2024-03-10 Added SerialCommunication object, set up framework for Keyboard emulation
2024-03-11 Added return statements, configured SerialCommunication keys for each switch
2024-03-12 Updated requirements with new switch-key mapping
2024-03-14 Formatting & requirement traceability
2024-03-14 Added electrical schematic
    [SystemElectricalSchematic.kicad_sch]
2024-04-04 First draft of README, Cfg_Types.h updated after soldered connections
2024-04-05 Added CAD files
    [RightEndCover.FCStd, RightEndCover.stl]
